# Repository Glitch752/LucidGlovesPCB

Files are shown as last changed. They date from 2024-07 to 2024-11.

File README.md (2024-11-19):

# LucidGlovesPCB
A PCB for [LucidVR](https://github.com/LucidVR/lucidgloves) prototype 5 haptic gloves.

## Parts required
|Item |Link |Quantity required for 2 gloves|Quantity to purchase|Total price (as of writing)|Variant |Notes |
|---|---|---|---|---|---|---|
|49E Hall Effect Sensors|https://www.aliexpress.us/item/3256806022182106.html |30 |1 |$5.28 |50pcs |3 per finger w/ splay |
|Neodymium magnets |https://www.aliexpress.us/item/3256804031680743.html |100 |1 |$2.44 |100pcs |Requires 5 per finger for flexion, +5 per finger for splay |
|Silicone Grips |https://www.amazon.com/Protectors-Fingertips-Fingertip-Paperwork-Instrument/dp/B09P1SV9BM|10 |1 |$6.96 |Pack of 50 |One per finger |
|Battery |https://www.amazon.com/gp/product/B094G1GL8T |2 |1 |$35.95 |Pack of 2 |1 per hand; can use pretty much any USB power bank with two 2.1A outputs |
|ESP-WROOM-32 |https://www.aliexpress.us/item/2251832678407407.html |2 |2 |$5.66 |ESP-WROOM-32D |1 per hand |
|MG90S Servo Motors |https://www.aliexpress.us/item/3256805639785749.html |10 |1 |$8.01 |MG90S-10pcs |5 per hand |
|10x15x4mm Bearings |https://www.aliexpress.us/item/3256802495161748.html |20 |2 |$26 |10pc 6700ZZ ABEC 1|2 per finger |
|CD74HC4067 Multiplexer |https://www.amazon.com/Ximimark-Digital-Multiplexer-Breakout-CD74HC4067/dp/B07K7JF3HX |2 |1 |$6.99 |Pack of 5 |1 per hand |
|3D printed parts |https://github.com/LucidVR/lucidgloves/wiki/Prototype-5-Beta-Printing-Guide |2 sets |- |Depends | | |

The total cost was $87.29 including batteries but excluding printed parts and the PCB as of writing.

You will also likely require:
- Solder and a soldering iron
- Dupont cables (or the connectors and a crimping kit to make your own for better cable management)
- Velcro (or an alternative way to secure the gloves)
- Foam (for comfort)
- Optionally some joysticks and buttons
- 4 short USB-C cables to attatch your batteries to the board if they don't come with some

## Images




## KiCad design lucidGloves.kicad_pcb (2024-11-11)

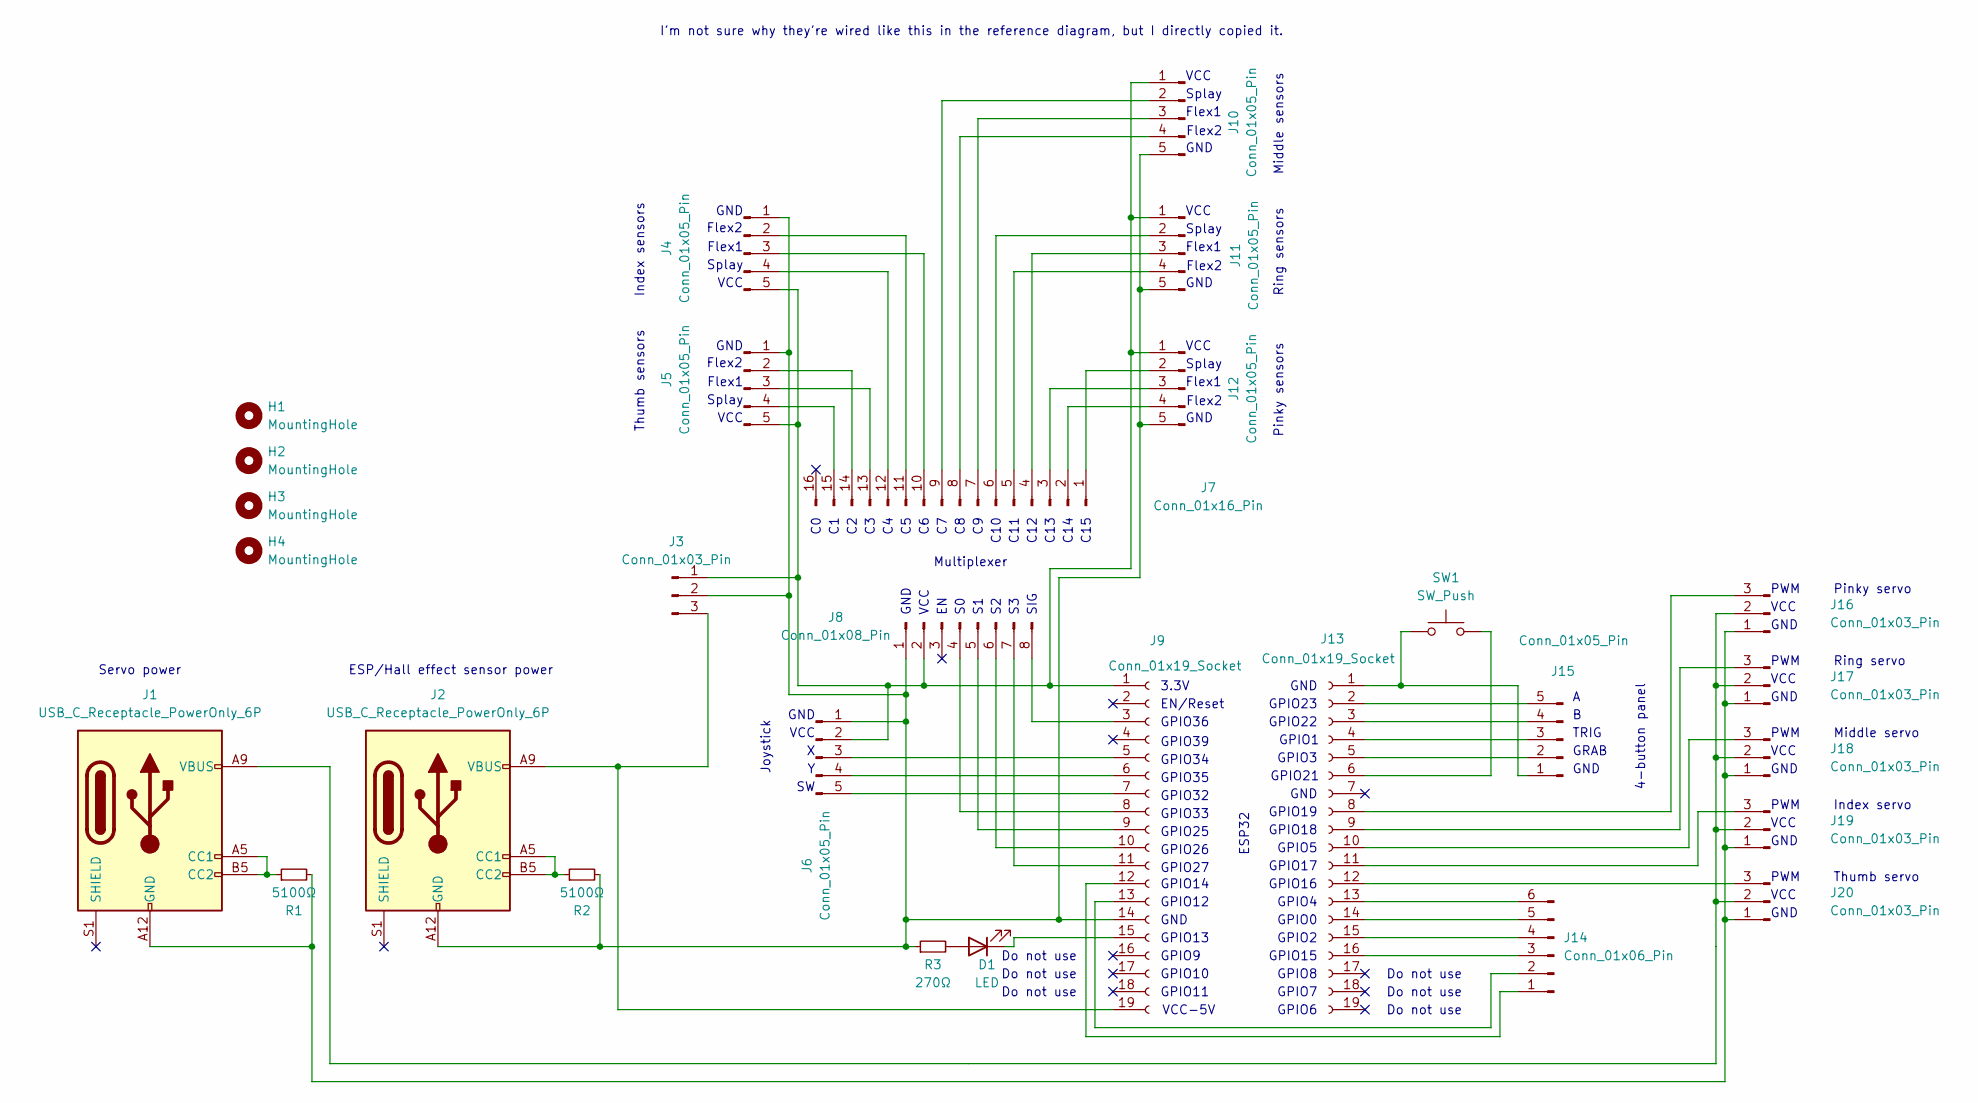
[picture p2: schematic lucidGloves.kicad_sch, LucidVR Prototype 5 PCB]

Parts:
D1: LED; LED_PLCC-2_3x2mm_AK; LCSC C2286
H1, H2, H3, H4: MountingHole; MountingHole_3.2mm_M3
J1, J2: USB_C_Receptacle_PowerOnly_6P; USB_C_Receptacle_GCT_USB4135-GF-A_6P_TopMnt_Horizontal; LCSC C2681548
J3: Conn_01x03_Pin; PinHeader_1x03_P2.54mm_Horizontal; LCSC C92159
J4, J5, J10, J11, J12: Conn_01x05_Pin; PinHeader_1x05_P2.54mm_Vertical; LCSC C5156614
J6, J15: Conn_01x05_Pin; PinHeader_1x05_P2.54mm_Horizontal; LCSC C138801
J7: Conn_01x16_Pin; PinHeader_1x16_P2.54mm_Vertical; LCSC C7501270
J8: Conn_01x08_Pin; PinHeader_1x08_P2.54mm_Vertical; LCSC C5156616
J9, J13: Conn_01x19_Socket; PinSocket_1x19_P2.54mm_Vertical; LCSC C319202
J14: Conn_01x06_Pin; PinHeader_1x06_P2.54mm_Horizontal; LCSC C56816
J16, J17, J18, J19, J20: Conn_01x03_Pin; PinHeader_1x03_P2.54mm_Vertical; LCSC C49257
R1, R2: 5100Ω; R_0402_1005Metric; LCSC C103079
R3: 270Ω; R_0402_1005Metric; LCSC C138294
SW1: SW_Push; SW_TH_Tactile_Omron_B3F-10xx; LCSC C271750

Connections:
unnamed: D1.2 (A), R3.2
unnamed: D1.1 (K), J9.15
unnamed: J1.A5 (CC1), J1.B5 (CC2), R1.1
unnamed: J2.A5 (CC1), J2.B5 (CC2), R2.1
unnamed: J2.A9 (VBUS), J2.B9 (VBUS), J3.3, J9.19
unnamed: J4.2, J7.11
unnamed: J4.3, J7.10
unnamed: J4.4, J7.12
unnamed: J5.2, J7.14
unnamed: J5.3, J7.13
unnamed: J5.4, J7.15
unnamed: J6.3, J9.5
unnamed: J6.4, J9.6
unnamed: J6.5, J9.7
unnamed: J8.4, J9.8
unnamed: J8.5, J9.9
unnamed: J8.6, J9.10
unnamed: J8.7, J9.11
unnamed: J8.8, J9.3
unnamed: J3.1, J4.5, J5.5, J6.2, J8.2, J9.1, J10.1, J11.1, J12.1
unnamed: J7.9, J10.2
unnamed: J7.7, J10.3
unnamed: J7.8, J10.4
unnamed: J2.A12 (GND), J2.B12 (GND), J3.2, J4.1, J5.1, J6.1, J8.1, J9.14, J10.5, J11.5, J12.5, R2.2, R3.1
unnamed: J7.6, J11.2
unnamed: J7.4, J11.3
unnamed: J7.5, J11.4
unnamed: J7.1, J12.2
unnamed: J7.3, J12.3
unnamed: J7.2, J12.4
unnamed: J13.1, J15.1, SW1.1
unnamed: J13.2, J15.5
unnamed: J13.3, J15.4
unnamed: J13.4, J15.3
unnamed: J13.5, J15.2
unnamed: J13.6, SW1.2
unnamed: J13.8, J16.3
unnamed: J13.9, J17.3
unnamed: J13.10, J18.3
unnamed: J13.11, J19.3
unnamed: J13.12, J20.3
unnamed: J13.13, J14.6
unnamed: J13.14, J14.5
unnamed: J13.15, J14.4
unnamed: J13.16, J14.3
unnamed: J9.12, J14.1
unnamed: J9.13, J14.2
unnamed: J1.A12 (GND), J1.B12 (GND), J16.1, J17.1, J18.1, J19.1, J20.1, R1.2
unnamed: J1.A9 (VBUS), J1.B9 (VBUS), J16.2, J17.2, J18.2, J19.2, J20.2

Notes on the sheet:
Flex1
GND
C15
SIG
GPIO14
Multiplexer
GPIO4
VCC
GPIO23
GPIO9
Pinky servo
Splay
GPIO39
GPIO34
GPIO35
GPIO26
Do not use
Flex2
GRAB
Index servo
GPIO10
VCC-5V
GPIO3
GPIO15
Servo power
Index sensors
GPIO12
GPIO27
ESP32
GPIO36
GPIO5
C10
GPIO13
GPIO1
GPIO16
GPIO2
C14
PWM
GPIO22
GPIO32

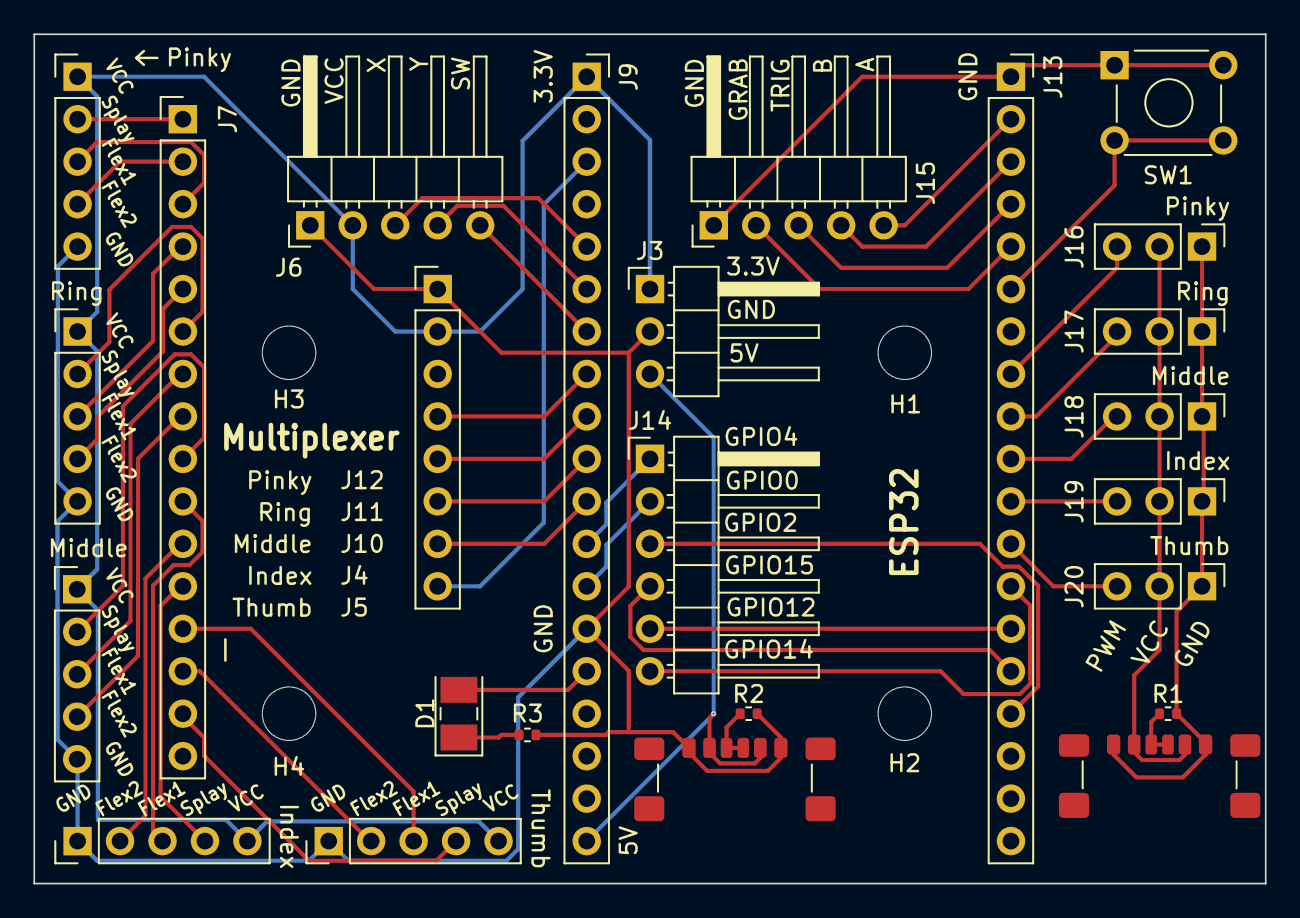
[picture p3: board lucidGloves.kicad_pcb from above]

Board: 2 copper layers, 73.7 x 50.8 mm, 29 parts (0 on the bottom side), 49 nets.

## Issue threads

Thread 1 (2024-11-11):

Part list

Nervtoetertoeter, 2024-11-11:
Hi,
You posted a cart.png file showing your order - can you post a part list too?
Regards,
Nervtoetertoeter

Glitch752, 2024-11-11:
This is a great call! I'm sorry that I neglected to add one.

I haven't fixed an oversight I found after receiving the PCB yet: the multiplexer pins are spaced for a different board than I'm using. I'll update the PCB and upload a part list when I have time this week.

Thanks!

Nervtoetertoeter, 2024-11-15:
I noticed the problem with the multiplexer too, but i'm going to use double row pin headers to enlarge the layout of the multiplexer and simply cut the lower legs of the second row, so I don't need not reproduce the pcb or buy another multiplexer. Hope this sketch helps to understand how I solved this issue:
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

Glitch752, 2024-11-19:
Added in dbd3a09 and 772ac46. Sorry that took me so long!

Closed 2024-11-19.

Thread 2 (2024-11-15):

prototype 5 cabling hall-sensors

Nervtoetertoeter, 2024-11-15:
Hi again,
Can you post a picture of how you did the cabling of the hall sensors? I got it pretty small, but it seems there're still to thick with the attached cables to be put side by side on one hand, so that splay can barely occur.
Bye!

Glitch752, 2025-01-14:
Whoops; I thought I responded to this a while ago but I apparently didn't. My apologies.

My lucid VR gloves aren't actually put together right now, so I unfortunately can't send a great picture... I'm super sorry!

I'm using thin 22 AWG stranded wire that is really flexible to avoid issues with them constraining finger motion. I didn't have any troubles keeping the wires apart, but maybe I'm misunderstanding what you're describing. If you could send an image, I could try to help; maybe 3D printed clips to keep the wires grouped per finger could work?

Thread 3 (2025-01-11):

Multiplexer correct on PCB?

Nervtoetertoeter, 2025-01-11:
Hi,
Pin 17 of the multiplexer is connected to the esp32 pin 14. Pin 18 should be connected to 3.3v (Pin1) of the esp, but it looks like the PCB connects pin 18 to 11 (gpio27) on the esp??? Or am I completely wrong?
Regards.

Glitch752, 2025-01-14:
I'm really sorry for the late response! I've been super busy lately and forgot to send something.

I suppose I should write better documentation, but unless I'm misunderstanding, it seems like you have the pins on the multiplexer backward. It's intended to be mounted upside down with the IC facing toward the circuit board so GND is connected to pin 14 and S3 is connected to GPIO27. My apologies if this creates any problems for you, especially considering you already had to adjust to fit the multiplexer model used 😅

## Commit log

2024-07-02 Initial project
    [lucidGloves.kicad_pcb, lucidGloves.kicad_sch]
2024-07-02 Change to KiCad 8, fix labels to be text elemnts
2024-07-02 Fix all ERC errors and warnings
    [lucidGloves.kicad_sch]
2024-07-02 Add footprints to schematic
    [lucidGloves.kicad_pcb, lucidGloves.kicad_sch]
2024-07-02 Mostly lay out PCB
    [lucidGloves.kicad_pcb, lucidGloves.kicad_sch]
2024-07-02 Correct PCB alignment and spacing
    [lucidGloves.kicad_pcb, lucidGloves.kicad_sch]
2024-07-02 Start routing wires and change USB C ports again
    [lucidGloves.kicad_pcb, lucidGloves.kicad_sch]
2024-07-03 Finish PCB
    [lucidGloves.kicad_pcb, lucidGloves.kicad_sch]
2024-07-03 Fix tiny placement issue
    [lucidGloves.kicad_pcb]
2024-07-03 Added servo/sensor labels and LucidVR logo
    [lucidGloves.kicad_pcb]
2024-07-03 Add gerber and drill files
    [lucidGloves-B_Cu.gbr, lucidGloves-B_Mask.gbr, lucidGloves-B_Silkscreen.gbr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]
2024-07-03 Many improvements and tweaks
    [lucidGloves-B_Cu.gbr, lucidGloves-B_Mask.gbr, lucidGloves-B_Silkscreen.gbr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]
2024-07-03 Tweaks for final JLCPCB order
    [lucidGloves-B_Cu.gbr, lucidGloves-B_Mask.gbr, lucidGloves-B_Silkscreen.gbr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]
2024-11-11 Fix multiplexer spacing
    [lucidGloves-B_Cu.gbr, lucidGloves-B_Mask.gbr, lucidGloves-B_Silkscreen.gbr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]
2024-11-19 Add part list CSV file
    [partList.csv]
